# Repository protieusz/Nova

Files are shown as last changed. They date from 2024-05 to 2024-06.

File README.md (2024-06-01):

# Nova
Nova, a [Buran-Ortho](https://github.com/ScatteredDrifter/Buran-Ortho/tree/main) variant that has a 25mm trackball sensor integrated into a 5mm switch plate and optional 3x EVQ roller encoders. Powered by integrated RP2040.

# Sponsorship
This Nova pcb/pcba is made possible by: PCBWay
Thank you PCBWay for your quality pcba/pcb service. For all you pcb/pcba services, you can always rely on PCBWay for your pcb prototyping needs.

# Featured On KBD News
https://kbd.news/Buran-Ortho-2371.html

# Description
Nova, a [Buran-Ortho](https://github.com/ScatteredDrifter/Buran-Ortho/tree/main) variant that is heavily modified on the PCB side of components placement and case and switch plate mod to accomodate for the 25mm trackball hole.  Blessing for mods have been granted by the original designer of Buran, ScatterDrifter and thick switch plate by Plant. Case mod was done on Ottimo's Bofa case, https://github.com/subottimale/Buran-Bofa-case/tree/main.  The follow mods were done to the case, switch plate and pcb:

-PCB RP2040 components were place, routed from scratch and also to accomodate the PMW3360 sensor using EasyEDA.

-Added EVQ roller encoders option x3 to the middle top 3 key switches. EC11 encoder footprints have been removed. Roller encoder, you will have to snip off the plastic bottom so that when you solder it will remain flush to the pcb.

-Switch plate was modded with a larger hole in the place of the former encoder location to accomodate for the integrated 25mm trackball holder module. NOTE: The 3x encoder square holes, you will need to modify them to widen the holes since I forgot to adjust those. You will either need to dremel it or melt it wide a bit to accomodate for the holes.

-Top case of the Bofa was modified with a larger hole in place of the former encoder placement.

- ~~QMK code was borrowed from [Ploopy Adept](https://github.com/qmk/qmk_firmware/tree/master/keyboards/ploopyco/madromys) and modified by adding the Nova's key matrix layout into the code. No changes were made to the trackball code.~~ I have decided to use aki27's [bally](https://github.com/aki27kbd/vial-qmk/tree/vial/keyboards/aki27/bally)'s code instead since the Ploopy code I ran into issues and too tired to get it working.  No support will be given for QMK code. I just copy pasted bally's code to my Nova matrix. For QMK support, I recommend asking the QMK discord community.

-Added 38 individual switch RGBs.

-As always print the pcb design at your own risk and no support will be given.

Full Production Pics:

D4AFC096-B288-4E2A-9FCC-9BD741920737
827E48CC-210B-4E32-AA6E-871CCC9DF78D
7421A98E-BB6E-4C39-A3ED-7C58B0D0783C
20E94940-8326-4AEA-AF0D-43A8B87361EF












Render & Test Fitting Pics:




Screenshot 2024-04-10 at 10 01 34 PM
Screenshot 2024-04-10 at 10 00 57 PM
Screenshot 2024-04-10 at 10 44 53 AM
Screenshot 2024-04-10 at 8 18 57 PM
Screenshot 2024-04-10 at 10 00 38 PM
Screenshot 2024-04-10 at 10 00 15 PM
Screenshot 2024-04-10 at 10 00 01 PM
Screenshot 2024-04-10 at 8 47 54 PM

PCB Renders:

Screenshot 2024-04-16 at 9 46 38 AM
Screenshot 2024-04-16 at 9 46 20 AM
Screenshot 2024-04-16 at 9 48 29 AM
Screenshot 2024-04-16 at 10 03 32 AM
Screenshot 2024-04-16 at 10 03 46 AM
Screenshot 2024-04-12 at 8 30 23 AM
Screenshot 2024-04-12 at 8 51 13 AM
Screenshot 2024-04-12 at 8 51 27 AM
Screenshot 2024-04-12 at 8 51 39 AM
Screenshot 2024-04-11 at 12 16 26 PM
Screenshot 2024-04-12 at 8 51 52 AM

# Build Guide

Needed Parts To Complete The Nova:

| Parts | Link |
| --- | --- |
| 38-41 x Switches | |
| 3 x EVQ Rollers Encoders (Optional)  | https://www.aliexpress.com/item/32990950196.html?spm=a2g0o.order_list.order_list_main.70.79251802LG9UyV  |
| 1 x Nova PCBA |  |
| 1 x PMW3360 Sensor | https://www.aliexpress.com/item/1005005355003386.html?spm=a2g0o.order_list.order_list_main.50.79251802LG9UyV  |
| 38-41 x Keycaps |  |
| 38 x RGB LEDs SK6812 MINI-E 12MA| https://www.aliexpress.com/item/1005003636607308.html?spm=a2g0o.order_list.order_list_main.65.79251802LG9UyV |
| Modified Bofu Top Case |  |
| Un-modifed Bofu Bottom Case |  |
| USB C Magnetic Connector (Recommended) | https://www.aliexpress.com/item/1005003156990314.html?spm=a2g0o.order_list.order_list_main.121.79251802LG9UyV |
| 10 x M2 Screws (Bottom Case) |  |
| M2 Screws (Switch Plate) | |
| 1 x 25mm POM, Perixx, Natural Gemstone, Billyard balls (Experiment yourself) | [POM](https://www.aliexpress.com/item/1005004594689539.html?spm=a2g0o.order_list.order_list_main.20.5b6b1802vG6F1R) |
| | [Mineral Stone](https://www.aliexpress.com/item/1005005241158203.html?spm=a2g0o.order_list.order_list_main.36.5b6b1802vG6F1R) |
| | [Billyard balls](https://www.aliexpress.com/item/1005005508968367.html?spm=a2g0o.order_list.order_list_main.81.5b6b1802vG6F1R) |
| Hot Inserts 3.2mm Diameter 3-4mm Length |https://www.aliexpress.com/item/1005005220632314.html?spm=a2g0o.order_list.order_list_main.327.1da21802wQGF0Y |

# NOTE: Before you solder anything, take the pcb out of the mailing box and plug into your computer to do a tweezer switch test to make sure all the key switches are working. It should all work since I pre-flashed the firmware myself and tested them before I ship out. Do not solder other stuff before you do the key testing first. You have been warned.

1. Soldering the PMW3360 Sensor:

Refer to the picture below on the orientation of the sensor and be wary of PIN 1. Do not mess up or else it will be hell to de-solder. Study the picture carefully before you solder or forever be sorry.

PMW3360 sensor goes at the back of the PCB as per picture below



Zoomed in on the sensor. Make sure the washed out greyish yellowish dot aka PIN 1 aligns with PIN 1 silkscreen labelled on the pcb. The number example AXX should be the orientaton of the picture.  On the right side, sideways should be the sensor model number. Make very sure of the orientation. No support will be given on how to de-solder and solder. Apply a yellow tape or painters tape on the sensor to secure it so that it is flush on the pcb and when you solder the pins, it will not move.



Zoomed Front Side PCB where the sensor lens will be installed




Remember to remove the yellow tape off the sensor after you solder it




2. After you soldered the PMW33660 sensor, test fit the NOVA pcb to the printed switch plate with 4 switches install on the 4 corners of the switch plate & the modifed Bofa top case friction fit with the switch plate. The reason is to test out your 25mm of whatever material ball you have with the top cover case ball holder to see if it works. Plug in the USB C of the PCB to test out duh. Put the 25mm ball on the top of the holder and go nuts on it. Make sure the cursor on your monitor moves smoothly. If it doesn't change to a different material balls. FYI due to the natural of tolerant the the 3D printer prints the PLA or Nylon, you will get different smoothness of the ball rolling results. I usually have the following material balls on hand with me: POM ball, Perixx 25mm ball, Mineral/stone ball & billyard balls, other balls that I have not mentioned. You can also put the lens of the PMW3360 sensor up towards the top side of the pcb. It will make the lens a tiny little bit closer to the bottom of the ball. It helps a little bit but not much. The main key is to find a compatible ball that works with your 3D printed case. Now is a good time to hot insert the M2 brass into your PLA printed case so that they can hold onto your M2 screws.

Fit your pcb top side towards the switch with the top case that is already installed as per picture for testing the trackball sensor with a 25mm ball. Picture is pretty self explainatory.






3. Once your PMW3360 sensor is working flawlessly, you can solder the 3 EVQ roller encoder which are "OPTIONAL".  Do not solder if you are not confident. No support will be given on how to solder and de-solder.  Before you solder the encoders, you will need to file or melt the square holes on the switch plate, a little wider since there were dimension errors when I design it. Do whatever it takes so that the encoder fits into the square hole. I have also included a step file I think which you can modify to make the hole wider.

4. Once the switch encoder holes are widen, then you need to flush clip the "leg" of the EVQ encoder so that when solder onto the pcb, the encoder will sit "FLUSH" on the pcb. I repeat, it will have to sit flush or else it will look very "FUGLY" slanted. After you cut the leg carefully with the flush cutter, make sure you even out the flushness with an Xactor knife. Then solder the thru holes of the encoder to the pcb.

5. Once you confirmed everything is working flawlessly, solder on all the switches attached to the switch plate, top case and pcb. DO NOT MILL MAX it, since the tiny gap of the hot swap Mill Max will cause the trackball sensor to not work and then you will cry. You have been warned.

6. Solder The LED RGBs Very Last!!!

The reason why I emphasize this is because if the orientation of the LEDs are solder wrong, the pcb will work at all until you de-solder it/correct the orientation or remove the wrong orientation LEDS before the pcb will start working again. Wrong orientation will create a short. Make very sure of your solder skill level before you solder the RGBs. De-solder the RGBs is another level of hell that you DO NOT want to go through. RGB LEDs are optional and only for asthetics and does not provide any "useful" functionality. No support will be given if you fuck up.

Here is a close up pic of the "notch" of the LED leg that should be solder on the "notch" or the "L" symbol on the pcb. The icon silk mask might not be super clear but you can make an educated guess.  DO NOT CONFUSE the "dot" and the "L" symbol being the same since the "dot" is 5 volts. Soldering them in reverse will cause a short. Also please refer to my Left and Right side RGB [diagram](https://github.com/protieusz/Nova/tree/main/Nova%20RGB%20Orientation) above. Solder the lowest "Uxx" LED first and then plug in to USB C to see if it lights up. If solder properly it should light super bloody RED in color.  If it doesn't light up, either reflow the solder or you F up your RGB. Best of luck!



7. Once everything else is working perfectly, Then screw the bottom case to the top case.

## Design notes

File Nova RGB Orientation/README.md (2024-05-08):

Soldering the optional RGBs for Nova.

Pay attention to the "notches" icon silkscreen & the "dots" icon silksreen.

Notches are the GROUND notch legs of the LEDS.

Dots are the 5v legs.

Do not mess them up or else your pcb will not work and you will have a headache removing the solder RGBs and resolder them. I will not provide any support for soldering skills. You have been warned.

The pictures are pretty self explainatory. If you don't have the confidence of soldering RGBs then don't do it. It is not the end of the world.

All RGBs are labelled. Start test out the lowest label number first. Solder the one and plug in and test it out. By default the RGB will light up RED if you solder it properly.

Good luck!

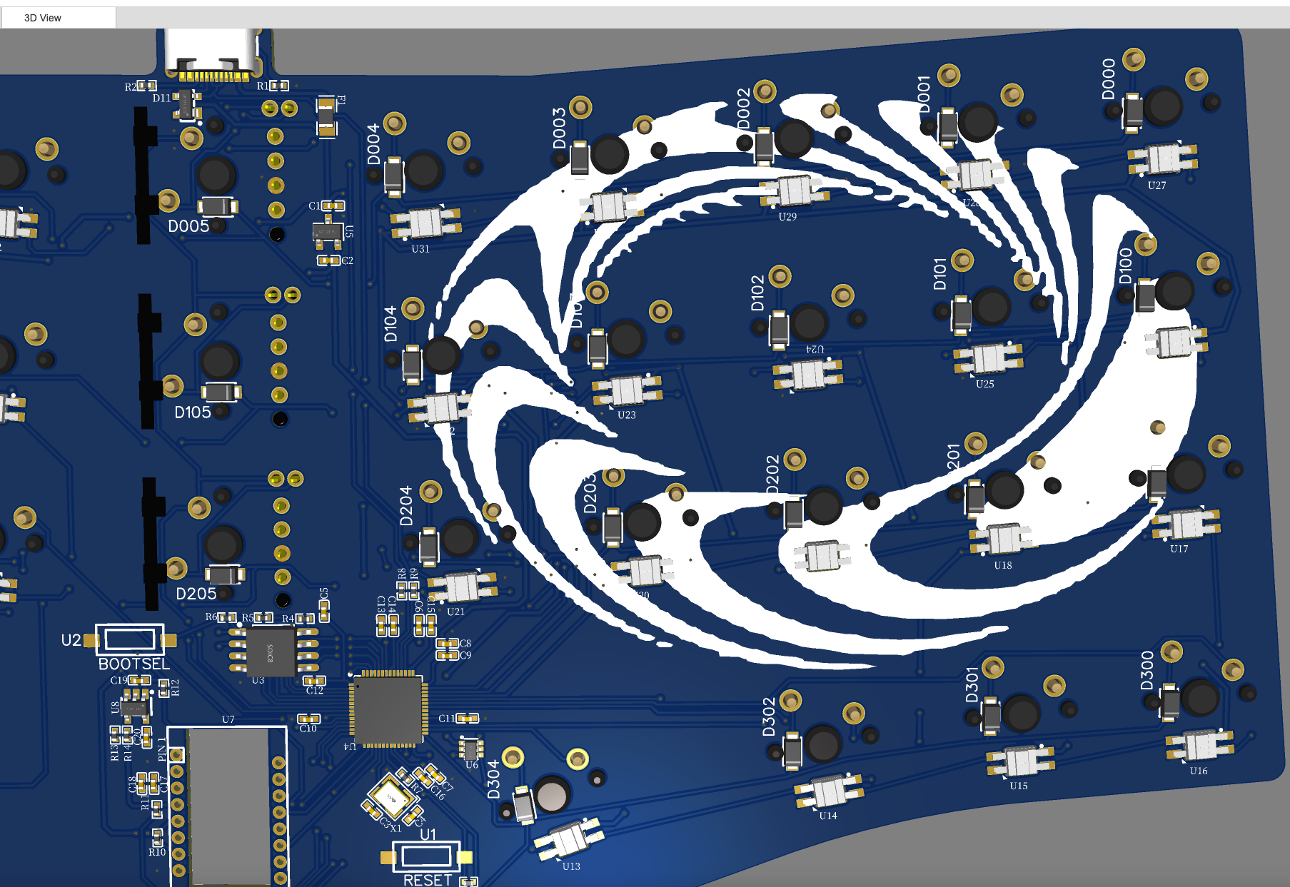
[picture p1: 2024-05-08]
Nova RGB Orientation/Left RGB Nova.png

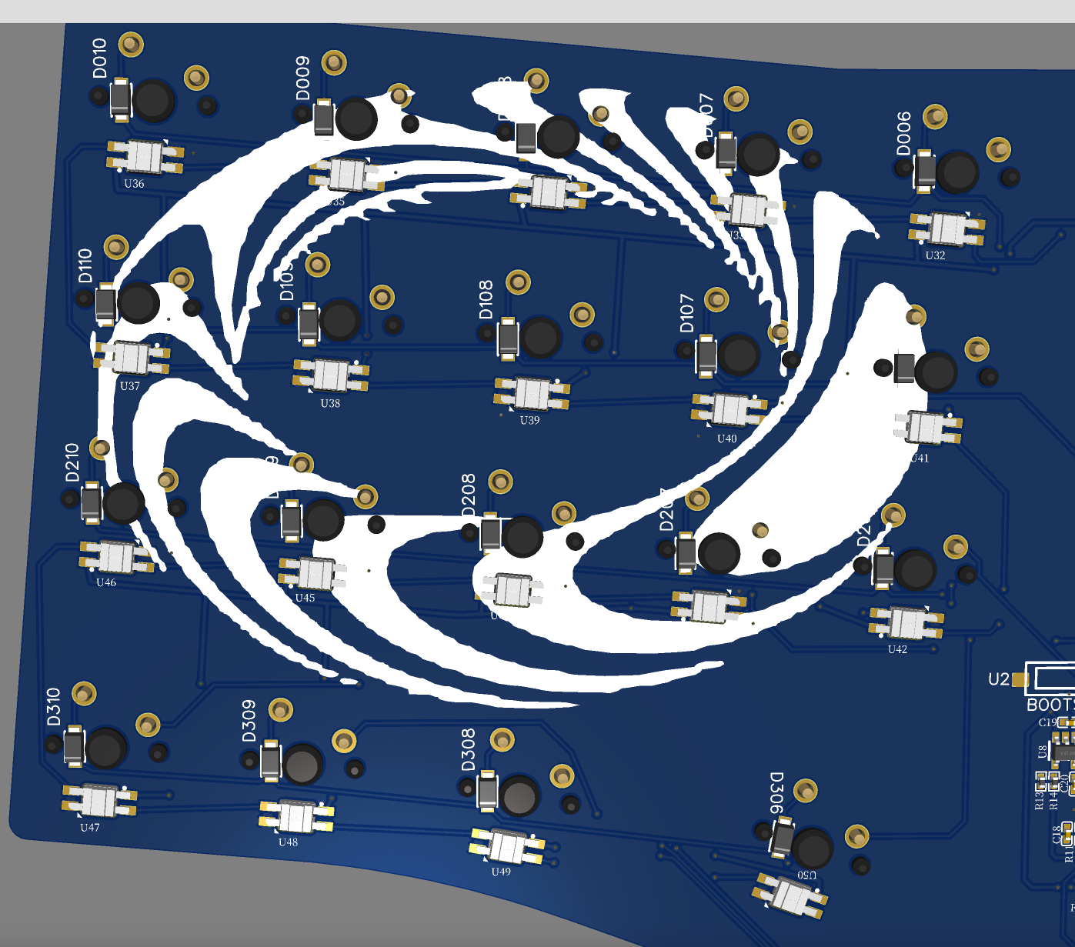
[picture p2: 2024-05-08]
Nova RGB Orientation/Right RGB Nova.png

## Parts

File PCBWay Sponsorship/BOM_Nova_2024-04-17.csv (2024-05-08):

ID | Name | Designator | Footprint | Quantity | Manufacturer Part | Manufacturer | Supplier | Supplier Part | Price | link
1 | Roll Encoder - EVQWGD001 | EC005,EC105,EC305 | EVQWGD001 ENCODER | 3 | EVQWGD001 | Panasonic | Aliexpress | EVQWGD001 |  |  | DO NOT Order or Assemble
2 | Switch | K000,K001,K002,K003,K004,K005,K006,K007,K008,K009,K010,K100,K101,K102,K103,K104,K105,K106,K107,K108,K109,K110,K200,K201,K202,K203,K204,K205,K206,K207,K208,K209,K210,K300,K301,K302,K304,K306,K308,K309,K310 | CHERRY_MX_100_MILLMAX | 41 |  |  |  |  |  |  | DO NOT Order or Assemble
3 | PMW3360DM-T2QU | U7 | PMW3360DM-T2QU.PACK | 1 | PMW3360DM-T2QU |  |  |  |  | http://www.pixart.com/upload/PMS0058-PMW3360DM-T2QU-NNDS-R1.30-06042016_20160902201411.pdf | DO NOT Order or Assemble
4 | 1uF | C1,C2,C5,C6,C9 | C0402 | 5 | CL05A105KA5NQNC | SAMSUNG(三星) | LCSC | C52923 | 0.004 | https://item.szlcsc.com/15869.html
5 | 22pF | C3,C4 | C0402 | 2 | 0402CG220J500NT | FH(风华) | LCSC | C1555 | 0.001 | https://item.szlcsc.com/15869.html
6 | 100nF | C7,C10,C11,C12,C13,C14,C15,C16 | C0402 | 8 | CL05B104KO5NNNC | SAMSUNG(三星) | LCSC | C1525 | 0.001 | https://item.szlcsc.com/15869.html
7 | 10uF | C8 | C0402 | 1 | CL05A106MQ5NUNC | SAMSUNG(三星) | LCSC | C15525 | 0.005 | https://item.szlcsc.com/15869.html
8 | 4.7uF | C17,C19,C20 | C0402 | 3 | CL05A475MP5NRNC | SAMSUNG(三星) | LCSC | C23733 | 0.005 | https://lcsc.com/eda_search?q=C23733&%26type=1&ref=editor
9 | 100nF | C18 | C0402 | 1 | CL05B104KB54PNC | SAMSUNG(三星) | LCSC | C307331 | 0.005 | https://lcsc.com/eda_search?q=C307331&%26type=1&ref=editor
10 | SM4007PL | D000,D001,D002,D003,D004,D005,D006,D007,D008,D009,D010,D100,D101,D102,D103,D104,D105,D106,D107,D108,D109,D110,D200,D201,D202,D203,D204,D205,D206,D207,D208,D209,D210,D300,D301,D302,D304,D306,D308,D309,D310 | SOD-123F_L2.8-W1.8-LS3.7-RD | 41 | SM4007PL | MDD | LCSC | C64898 | 0.007 | https://item.szlcsc.com/60254.html
11 | PRTR5V0U2X,215 | D11 | SOT-143_L2.9-W1.3-P1.92-LS2.3-BR | 1 | PRTR5V0U2X,215 | Nexperia(安世) | LCSC | C12333 | 0.11 | https://item.szlcsc.com/280548.html
12 | BSMD0805-020-15V | F1 | F0805 | 1 | BSMD0805-020-15V | BHFUSE(佰宏) | LCSC | C883103 | 0.04 | https://item.szlcsc.com/343298.html
13 | 5.1kΩ | R1,R2,R3,R4,R5 | R0402 | 5 | 0402WGF5101TCE | UNI-ROYAL(厚声) | LCSC | C25905 | 0.001 | https://item.szlcsc.com/323315.html
14 | 1kΩ | R6,R7 | R0402 | 2 | 0402WGF1001TCE | UNI-ROYAL(厚声) | LCSC | C11702 | 0.001 | https://item.szlcsc.com/323315.html
15 | 27Ω | R8,R9 | R0402 | 2 | 0402WGF270JTCE | UNI-ROYAL(厚声) | LCSC | C25100 | 0.001 | https://item.szlcsc.com/323315.html
16 | 10kΩ | R10,R12,R13 | R0402 | 3 | 0402WGF1002TCE | UNI-ROYAL(厚声) | LCSC | C25744 | 0.001 | https://lcsc.com/eda_search?q=C25744&%26type=1&ref=editor
17 | 39Ω | R11 | R0402 | 1 | 0402WGJ0390TCE | UNI-ROYAL(厚声) | LCSC | C25164 |  | https://lcsc.com/eda_search?q=C25164&%26type=1&ref=editor
18 | 15kΩ | R14 | R0402 | 1 | 0402WGF1502TCE | UNI-ROYAL(厚声) | LCSC | C25756 | 0.001 | https://lcsc.com/eda_search?q=C25756&%26type=1&ref=editor
19 | RESET | U1 | RESET SWITCH | 1 |  |  |  |  |  |  | DO NOT Order or Assemble
20 | BOOT | U2 | RESET SWITCH | 1 |  |  |  |  |  |  | DO NOT Order or Assemble
21 | W25Q128JVSIQTR | U3 | SOIC-8_L5.3-W5.3-P1.27-LS8.0-BL | 1 | W25Q128JVSIQ | WINBOND(华邦) | LCSC | C97521 | 0.583 | https://item.szlcsc.com/63461.html
22 | RP2040 | U4 | LQFN-56_L7.0-W7.0-P0.4-EP | 1 | RP2040 | Raspberry Pi(树莓派) | LCSC | C2040 | 0.988 | https://atta.szlcsc.com/upload/public/pdf/source/20210621/C2040_96F425825606B7957D87DD32E2512CA9.pdf
23 | XC6206P332MR | U5 | SOT-23-3_L2.9-W1.6-P1.90-LS2.8-BR | 1 | XC6206P332MR | TOREX(特瑞仕) | LCSC | C5446 | 0.096 | https://item.szlcsc.com/14454.html
24 | AP2127K-ADJTRG1 | U8 | SOT-23-5_L3.0-W1.7-P0.95-LS2.8-BR | 1 | AP2127K-ADJTRG1 | DIODES(美台) | LCSC | C96343 | 0.069 | https://lcsc.com/eda_search?q=C96343&%26type=1&ref=editor
25 | TYPE-C-31-M-12 | USBC1 | USB-C_SMD-TYPE-C-31-M-12 | 1 | TYPE-C-31-M-12 | 韩国韩荣 | LCSC | C165948 | 0.158 | https://so.szlcsc.com/global.html?c=&k=C165948
26 | 12MHz | X1 | OSC-SMD_4P-L3.2-W2.5-BL | 1 | X322512MSB4SI | YXC(扬兴晶振) | LCSC | C9002 | 0.058 | https://item.szlcsc.com/15866.html
27 | SN74LVC1T45QDCKRQ1 | U6 | SC-70-6_L2.0-W1.3-P0.65-LS2.1-BR | 1 | SN74LVC1T45QDCKRQ1 | TI(德州仪器) | LCSC | C139353 | 0.354 | https://lcsc.com/eda_search?q=C139353&%26type=1&ref=editor
28 | SK6812MINI-E_C5149201 | U13,U14,U15,U16,U17,U18,U19,U20,U21,U22,U23,U24,U25,U26,U27,U28,U29,U30,U31,U32,U33,U34,U35,U36,U37,U38,U39,U40,U41,U42,U43,U44,U45,U46,U47,U48,U49,U50 | LED-SMD_L3.2-W2.8-TR | 38 | SK6812MINI-E | 欧思科光电 | LCSC | C5149201 | 0.163 | https://lcsc.com/eda_search?q=C5149201&%26type=1&ref=editor | DO NOT Order or Assemble

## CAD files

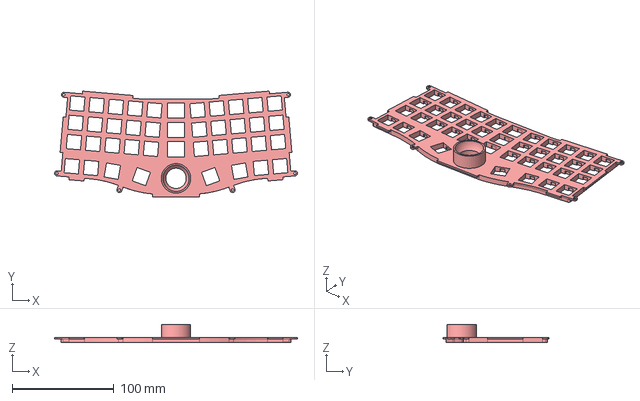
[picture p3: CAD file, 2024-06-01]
Corrected Case Nova/Buran_Universal_Mount_Plate_thick Modded w Trackball.step
239.2 x 104.2 x 17.8 mm

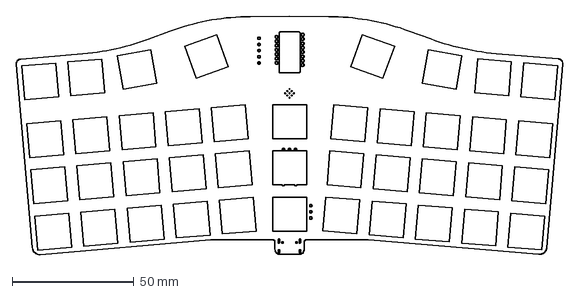
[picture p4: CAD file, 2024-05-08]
For PCB Design Production/Nova Buran PCB Sketch.dxf
224.4 x 97.8 mm

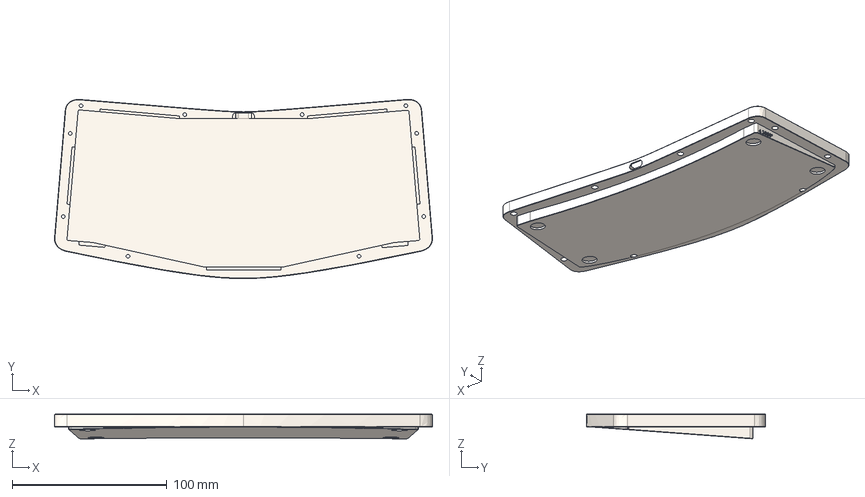
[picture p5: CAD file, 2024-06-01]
Corrected Case Nova/Buran Bofa Non Modded Bottom Case.step
244.5 x 116.0 x 16.0 mm

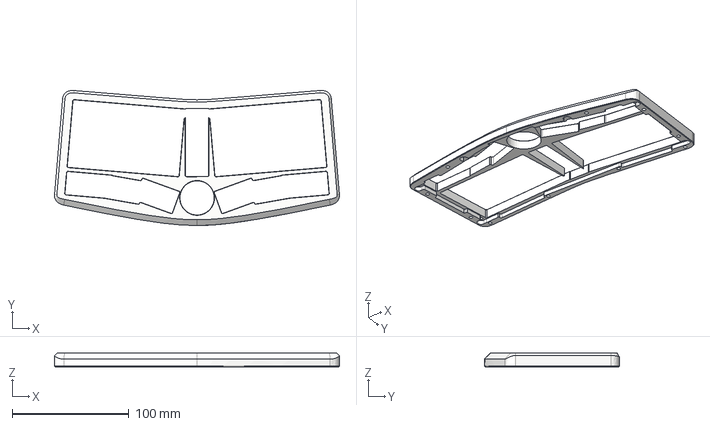
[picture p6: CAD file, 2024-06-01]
Corrected Case Nova/Buran Bofa Top Modded Large Trackball Hole.step
244.5 x 116.0 x 11.7 mm

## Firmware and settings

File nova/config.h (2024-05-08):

// Copyright 2024 ProtieusKeebs
// SPDX-License-Identifier: GPL-2.0-or-later

#pragma once

#define RP2040_BOOTLOADER_DOUBLE_TAP_RESET // Activates the double-tap behavior
#define RP2040_BOOTLOADER_DOUBLE_TAP_RESET_TIMEOUT 200U // Timeout window in ms in which the double tap can occur.

#ifdef COMBO_ENABLE
#    define COMBO_COUNT 2
#    define COMBO_TERM 200
#endif

/* Encoder */
//#define ENCODERS_PAD_A { GP11 }
//#define ENCODERS_PAD_B { GP12 }
//#define ENCODER_RESOLUTION 4

/* Matrix*/
//#define MATRIX_COL_PINS { GP25, GP24, GP23, GP22, GP21, GP26, GP27, GP20, GP19, GP18, GP17, GP16, GP13 }
//#define MATRIX_ROW_PINS { GP28, GP10, GP14, GP15 }

/* COL2ROW, ROW2COL */
//#define DIODE_DIRECTION COL2ROW


/* Set 0 if debouncing isn't needed */
//#define DEBOUNCE 5


/* Mechanical locking support. Use KC_LCAP, KC_LNUM or KC_LSCR instead in keymap (Very Important for Scroll Lock!!!) */
#undef LOCKING_SUPPORT_ENABLE
/* Locking resynchronize hack */
#undef LOCKING_RESYNC_ENABLE


/* RGB LED */
//#define WS2812_PIO_USE_PIO1
#define WS2812_DI_PIN GP17

#ifdef RGBLIGHT_ENABLE
    #define RGBLIGHT_LED_COUNT 38
    #define RGBLIGHT_LIMIT_VAL 80
    #define RGBLIGHT_HUE_STEP 10
    #define RGBLIGHT_SAT_STEP 17
    #define RGBLIGHT_VAL_STEP 17

    #define RGBLIGHT_EFFECT_BREATHING
    #define RGBLIGHT_EFFECT_RAINBOW_MOOD
    #define RGBLIGHT_EFFECT_RAINBOW_SWIRL
    #define RGBLIGHT_EFFECT_SNAKE
    #define RGBLIGHT_EFFECT_KNIGHT
    #define RGBLIGHT_EFFECT_CHRISTMAS
    #define RGBLIGHT_EFFECT_STATIC_GRADIENT
    #define RGBLIGHT_EFFECT_TWINKLE
    #define RGBLIGHT_EFFECT_ALTERNATING
#endif


/* Trackball */

#ifdef POINTING_DEVICE_ENABLE
#    define SPI_DRIVER SPID1
#    define SPI_SCK_PIN GP14
#    define SPI_MISO_PIN GP12
#    define SPI_MOSI_PIN GP15

#endif

#ifndef PMW33XX_CS_PIN
#    define PMW33XX_CS_PIN GP13
#endif
#define POINTING_DEVICE_INVERT_X
#define POINTING_DEVICE_INVERT_Y
#define POINTING_DEVICE_ROTATION_180

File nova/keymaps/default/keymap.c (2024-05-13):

/* Copyright 2023 Colin Lam (Ploopy Corporation)
 * Copyright 2020 Christopher Courtney, aka Drashna Jael're  (@drashna) <drashna@live.com>
 * Copyright 2019 Sunjun Kim
 *
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
 * You should have received a copy of the GNU General Public License
 * along with this program.  If not, see <http://www.gnu.org/licenses/>.
 */
#include QMK_KEYBOARD_H

enum combo_events {
  COMBO_DEL,
  COMBO_ESC,
  COMBO_LENGTH
};
uint16_t COMBO_LEN = COMBO_LENGTH;

const uint16_t PROGMEM combo_del[] = {KC_Y, KC_H, COMBO_END};
const uint16_t PROGMEM combo_esc[] = {KC_T, KC_G, COMBO_END};

combo_t key_combos[] = {
  [COMBO_DEL] = COMBO(combo_del, KC_DEL),
  [COMBO_ESC] = COMBO(combo_esc, KC_ESC),
};

layer_state_t layer_state_set_user(layer_state_t state) {
    return update_tri_layer_state(state, 1, 2, 3);
} 

const uint16_t PROGMEM keymaps[][MATRIX_ROWS][MATRIX_COLS] = {
    
    [0] = LAYOUT(
        KC_Q,         KC_W, KC_E,    KC_R,    KC_T,                      SCRL_MO,               KC_Y,          KC_U,          KC_I,     KC_O,   KC_P,
        KC_A,         KC_S, KC_D,    KC_F,    KC_G,                      KC_MS_BTN1,            KC_H,          KC_J,          KC_K,     KC_L,   KC_SCLN,
        LSFT_T(KC_Z), KC_X, KC_C,    KC_V,    KC_B,                      KC_MS_BTN2,            KC_N,          KC_M,          KC_COMMA, KC_DOT, RSFT_T(KC_SLSH),
        KC_ESC,       KC_LGUI, KC_LCTL,       LT(1,KC_BSPC),                                    LT(2,KC_SPC),                 (KC_ENT), KC_LALT, KC_CAPS                        
    ),
    [1] = LAYOUT(
        KC_1,    KC_2,    KC_3,    KC_4,    KC_5,                  _______,                   KC_6,     KC_7,    KC_8,    KC_9,    KC_0,
        KC_TAB,  _______, _______, _______, _______,               _______,                   KC_MINS,  KC_EQL,  KC_LBRC, KC_RBRC, KC_QUOT,
        _______, SCRL_MO, KC_MS_BTN2, KC_MS_BTN1, _______,         _______,                   KC_TILD,  KC_GRV,  _______, _______, KC_BSLS,
        _______, _______, _______,          _______,                                          _______,           _______, _______, _______                  
    ),
    [2] = LAYOUT(
        KC_EXLM, KC_AT,   KC_HASH, KC_DLR,  KC_PERC,          _______,                   KC_CIRC, KC_AMPR, KC_ASTR, KC_LPRN, KC_RPRN,
        RGB_VAI,  RGB_SAI,  RGB_HUI,  RGB_SPI, RGB_MOD,       _______,                   RGB_TOG,  _______,  _______, _______, _______, 
        RGB_VAD,  RGB_SAD,  RGB_HUD,  RGB_SPD, RGB_RMOD,      _______,                   _______,  _______, _______, _______, _______,
        _______, _______,  _______,          _______,                                    _______,           _______, _______, _______
    ),
    [3] = LAYOUT(
        _______, KC_UP, _______, _______, _______,               _______,                    KC_F1,   KC_F2,   KC_F3,   KC_F4,   KC_PSCR,
        KC_LEFT, KC_DOWN, KC_RIGHT, _______, _______,            _______,                    KC_F5,   KC_F6,   KC_F7,   KC_F8,   KC_F9,
        _______, _______, ROT_L15, ROT_R15, CPI_SW,              _______,                    KC_F10,  KC_F11,  KC_F12,  _______, _______,
        _______, _______, _______,            _______,                                       _______,          _______, _______, _______
    )
};

#ifdef ENCODER_MAP_ENABLE
const uint16_t PROGMEM encoder_map[][NUM_ENCODERS][NUM_DIRECTIONS] = {
    [0] =   { ENCODER_CCW_CW(KC_VOLD, KC_VOLU), ENCODER_CCW_CW(KC_MS_WH_DOWN, KC_MS_WH_UP), ENCODER_CCW_CW(KC_MS_WH_LEFT, KC_MS_WH_RIGHT) },
    [1] =   { ENCODER_CCW_CW(KC_TRNS, KC_TRNS), ENCODER_CCW_CW(KC_TRNS, KC_TRNS), ENCODER_CCW_CW(KC_TRNS, KC_TRNS) },
    [2] =   { ENCODER_CCW_CW(KC_TRNS, KC_TRNS), ENCODER_CCW_CW(KC_TRNS, KC_TRNS), ENCODER_CCW_CW(KC_TRNS, KC_TRNS) },
    [3] =   { ENCODER_CCW_CW(KC_TRNS, KC_TRNS), ENCODER_CCW_CW(KC_TRNS, KC_TRNS), ENCODER_CCW_CW(KC_TRNS, KC_TRNS) },    
};
#endif

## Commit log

2024-05-08 Current working firmware
2024-05-08 Production Files
    [BOM_Nova_2024-04-17.csv, PickAndPlace_PCB_Nova_RGBs_2024-04-17.csv]
2024-05-08 Modified Buran Bofa Case and plate Step
    [Buran Bofa Bottom.step, Buran Bofa Top.step, Buran_Top_Mount_Plate.dxf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]
2024-05-08 PCB DXF outline
    [Nova Buran PCB Sketch.dxf]
2024-05-08 LEDs soldering orientation
2024-06-01 Correct Case Step Files for Nova
    [Buran Bofa Non Modded Bottom Case.step, Buran Bofa Top Modded Large Trackball Hole.step, Buran_Universal_Mount_Plate_thick Modded w Trackball.step]

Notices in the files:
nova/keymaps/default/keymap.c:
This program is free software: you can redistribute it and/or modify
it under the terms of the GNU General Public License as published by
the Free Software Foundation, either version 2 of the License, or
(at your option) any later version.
